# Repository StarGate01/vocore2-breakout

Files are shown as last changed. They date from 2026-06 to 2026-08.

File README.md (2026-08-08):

# vocore2-breakout

KiCad breakout board for the VoCore2 module (MT7628AN SoC).

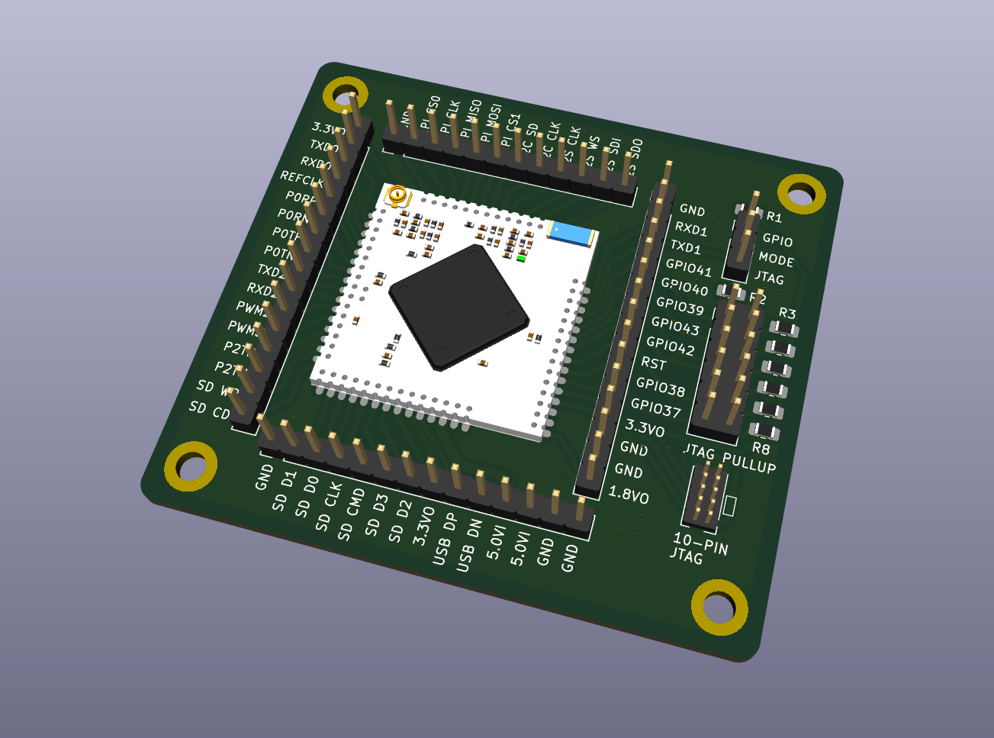
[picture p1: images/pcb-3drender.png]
PCB 3D render

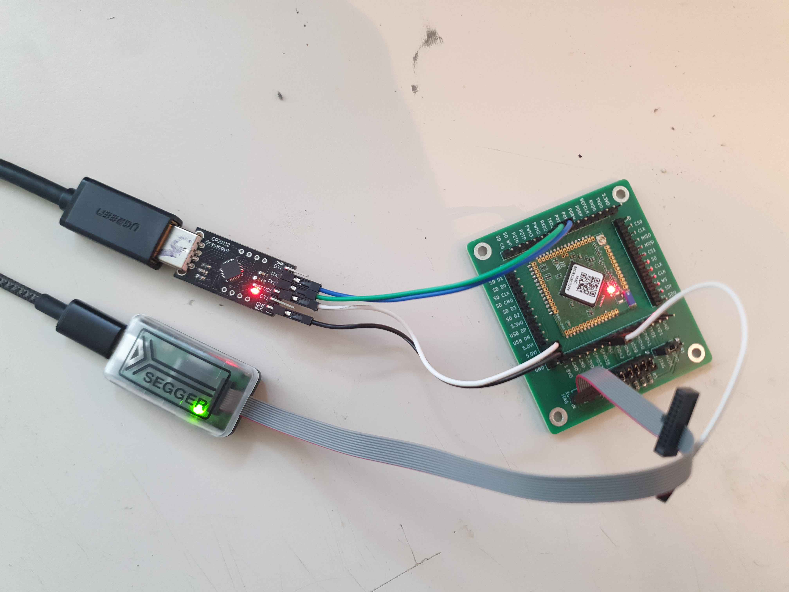
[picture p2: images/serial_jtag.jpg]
Serial and JTAG


## JTAG Connector (J-Link EDU Mini)

J6 is a 2×5 1.27 mm pitch header wired to the standard 9-pin ARM Cortex debug connector used by the J-Link EDU Mini.

| Pin | Signal | Notes |
|-----|---|---|
| 1 | `+3V3` | VTref - sense only, do not power board from here |
| 2 | `JTAG_TMS` | MT7628 `GPIO41` / `EPHY_LED2_N_JTMS` |
| 3 | `GND` | |
| 4 | `JTAG_CLK` | MT7628 `GPIO40` / `EPHY_LED3_N_JTCLK` |
| 5 | `GND` | |
| 6 | `JTAG_TDO` | MT7628 `GPIO43` / `EPHY_LED0_N_JTDO` |
| 7 | NC | KEY position - no pin on J-Link EDU Mini |
| 8 | `JTAG_TDI` | MT7628 `GPIO42` / `EPHY_LED1_N_JTDI` |
| 9 | `JTAG_TRST` | MT7628 `GPIO39` / `EPHY_LED4_N_JTRST_N` |
| 10 | `RESET` | MT7628 pin 138 / `PORST_N` (system reset, active-low) |

### J-Link EDU Mini reset pin specialities

The J-Link EDU Mini uses the **9-pin Cortex-M variant** of the connector, not the full 20-pin JTAG header:

- **Pin 7** is a physical key (no pin present). Not connected.
- **Pin 9** is repurposed by Segger as **nTRST** (JTAG TAP reset, active-low). In the standard Cortex-M spec pin 9 is NC; Segger uses it to support targets that need hardware TRST. Wire to `JTRST_N` (`GPIO39`).
- **Pin 10** is **nRESET** (system reset, active-low). Wire to `PORST_N`.

`WDT_RST_N` (`GPIO37` / MT7628 pin 137) appears adjacent to `PORST_N` and `JTRST_N` on the VoCore2 right-side connector and was considered for pin 9.

The vendor's JTAG how-to uses `WDT_RST_N` as "TRST" in their OpenOCD `sysfsgpio` config. This works because their setup is one VoCore2 bit-banging GPIOs to debug another - the host just needs two GPIO outputs to toggle, and driving `WDT_RST_N` low from an external GPIO triggers a full chip reset which also resets the JTAG TAP. OpenOCD's `sysfsgpio` driver doesn't care what hardware the signal is physically connected to; it just toggles the GPIO.

The J-Link is a hardware probe that follows the ARM Cortex debug connector spec strictly: pin 9 (`nTRST`) is driven by J-Link silicon to reset *only the JTAG TAP*, and the probe asserts and de-asserts it independently during normal debug sessions. If pin 9 connects to `WDT_RST_N`, every `nTRST` assertion by the J-Link triggers a full watchdog system reset, killing the debug session. `WDT_RST_N` is also a chip *output* when the watchdog fires, so the J-Link driving it creates a bus conflict. `JTRST_N` (`GPIO39`) resets only the TAP and has no output driver conflict.

### Pull-up resistors

All five JTAG signals (`TMS`, `TCK`, `TDI`, `TDO`, `TRST`) need pull-ups to 3V3. `RESET` (`PORST_N`) does not need external pull-ups from the breakout.

### OpenOCD configuration

OpenOCD requires third-party target scripts for the MT7628 - the standard script directory does not include this SoC. Clone [mtk-openwrt/openocd-scripts](https://github.com/mtk-openwrt/openocd-scripts) and point `OPENOCD_SCRIPTS` at it. This provides `mt7628.cfg` along with the `cpu_pll_init` and `dram_init` TCL helpers needed to bring up the PLL and DDR2 after halting the CPU via JTAG.

```sh
openocd -f interface/jlink.cfg \
        -c "transport select jtag" \
        -c "adapter speed 100" \
        -c "reset_config trst_and_srst separate srst_nogate connect_assert_srst" \
        -f mt7628.cfg \
        -c "init" \
        -c "reset halt" \
        -c "wait_halt 10000"
```

`adapter speed 100` - the MT7628 PLL is not running at reset; the JTAG clock source is the raw 40 MHz crystal. 100 kHz is conservative enough to be reliable in that window.

`reset_config trst_and_srst separate srst_nogate connect_assert_srst` - `connect_assert_srst` holds SRST (PORST_N) asserted when OpenOCD first connects, keeping the system in reset while the JTAG TAP initializes. `srst_nogate` keeps TCK running during SRST so OpenOCD can set the `EJTAGBOOT` instruction before releasing SRST. When SRST releases, the CPU starts with EJTAGBOOT active, enters the EJTAG debug ROM, and halts before its first instruction.

## TXD1 JTAG mode selector

MT7628 `GPIO13` / `TXD1` (VoCore2 pad `PR01`) is sampled at power-on reset to determine whether the `EPHY_LED` pins (`GPIO39`–`GPIO43`) operate as Ethernet LEDs or as the JTAG interface.

| `TXD1` at boot | Mode |
|---|---|
| HIGH (3V3) | Normal - `EPHY_LED` pins as Ethernet LEDs, **JTAG disabled** |
| LOW (GND) | **JTAG enabled** - `EPHY_LED` pins as `TMS`/`TCK`/`TDI`/`TDO`/`TRST` |

`JP1` is a 3-pin jumper with 4.7 kΩ resistors on both options:

| `JP1` position | `TXD1` | JTAG |
|---|---|---|
| 1-2 ("GPIO", default) | HIGH via `R1` (4K7 to `+3V3`) | Disabled |
| 2-3 ("JTAG") | LOW via `R2` (4K7 to `GND`) | **Enabled** |

Warning: JTAG mode breaks SD/eMMC on the EPHY pads.`TXD1` low (`DBG_JTAG_MODE=0`) does more than swap the `EPHY_LED` pins to JTAG, it puts the whole EPHY block into JTAG/debug state. If SD/eMMC is then muxed onto the EPHY pads ("IoT" mode, e.g. VoCore2's SD lines), the card stops responding. This is a hardware mutual-exclusion, not a software setting, JTAG and SD-on-EPHY cannot be used at the same time. Change the jumper after flashing to put the board into normal operation.

### VoCore2 module modification required

The stock VoCore2 module has **`R9` populated** (pull-up, 4.7 kΩ to 3V3) which holds `TXD1` high and disables JTAG. To use JTAG:

1. Remove `R9` from the VoCore2 module (eliminates the internal pull-up).
2. Set `JP` to position 2-3 on the breakout.

The breakout `JP` then has sole control over `TXD1` with no internal resistor fighting it. Leaving `R9` on the module while setting `JP` to 2-3 creates a voltage divider (~1.65 V, undefined logic level).

The original VoCore2 JTAG how-to describes moving `R9` to the `R6` footprint (a pull-down). With `R9` removed entirely and `JP` at 2-3, the effect is the same.

## Fabrication

Gerber files are in the `gerber/` directory and can be sent directly to a PCB manufacturer.

Before assembly, it is recommended to bake the VoCore2 module at 120 °C for at least 12 hours to drive out moisture. However it works just as well without.

The VoCore2 module must be reflowed using hot air, do not use a soldering iron. The DDR2 on the module is ESD-sensitive and iron leakage current can cause permanent damage. Reflow temperature must not exceed 260 °C for more than 10 seconds.

The resistors can be reflowed together with the VoCore2 module or soldered normally with an iron. The through-hole pin headers are soldered normally. Take special care with the JTAG header (J6): it uses a 1.27 mm pitch fine-pitch header where adjacent pins are easy to bridge accidentally. Inspect with a loupe or microscope after soldering.

## References

- [J-Link EDU Mini KB](https://kb.segger.com/J-Link_EDU_Mini)
- [9-pin JTAG/SWD connector](https://kb.segger.com/9-pin_JTAG/SWD_connector)
- [VoCore2 pinout](https://vocore.io/v2.html)
- [VoCore2 JTAG how-to](https://vonger.cn/?p=14897)

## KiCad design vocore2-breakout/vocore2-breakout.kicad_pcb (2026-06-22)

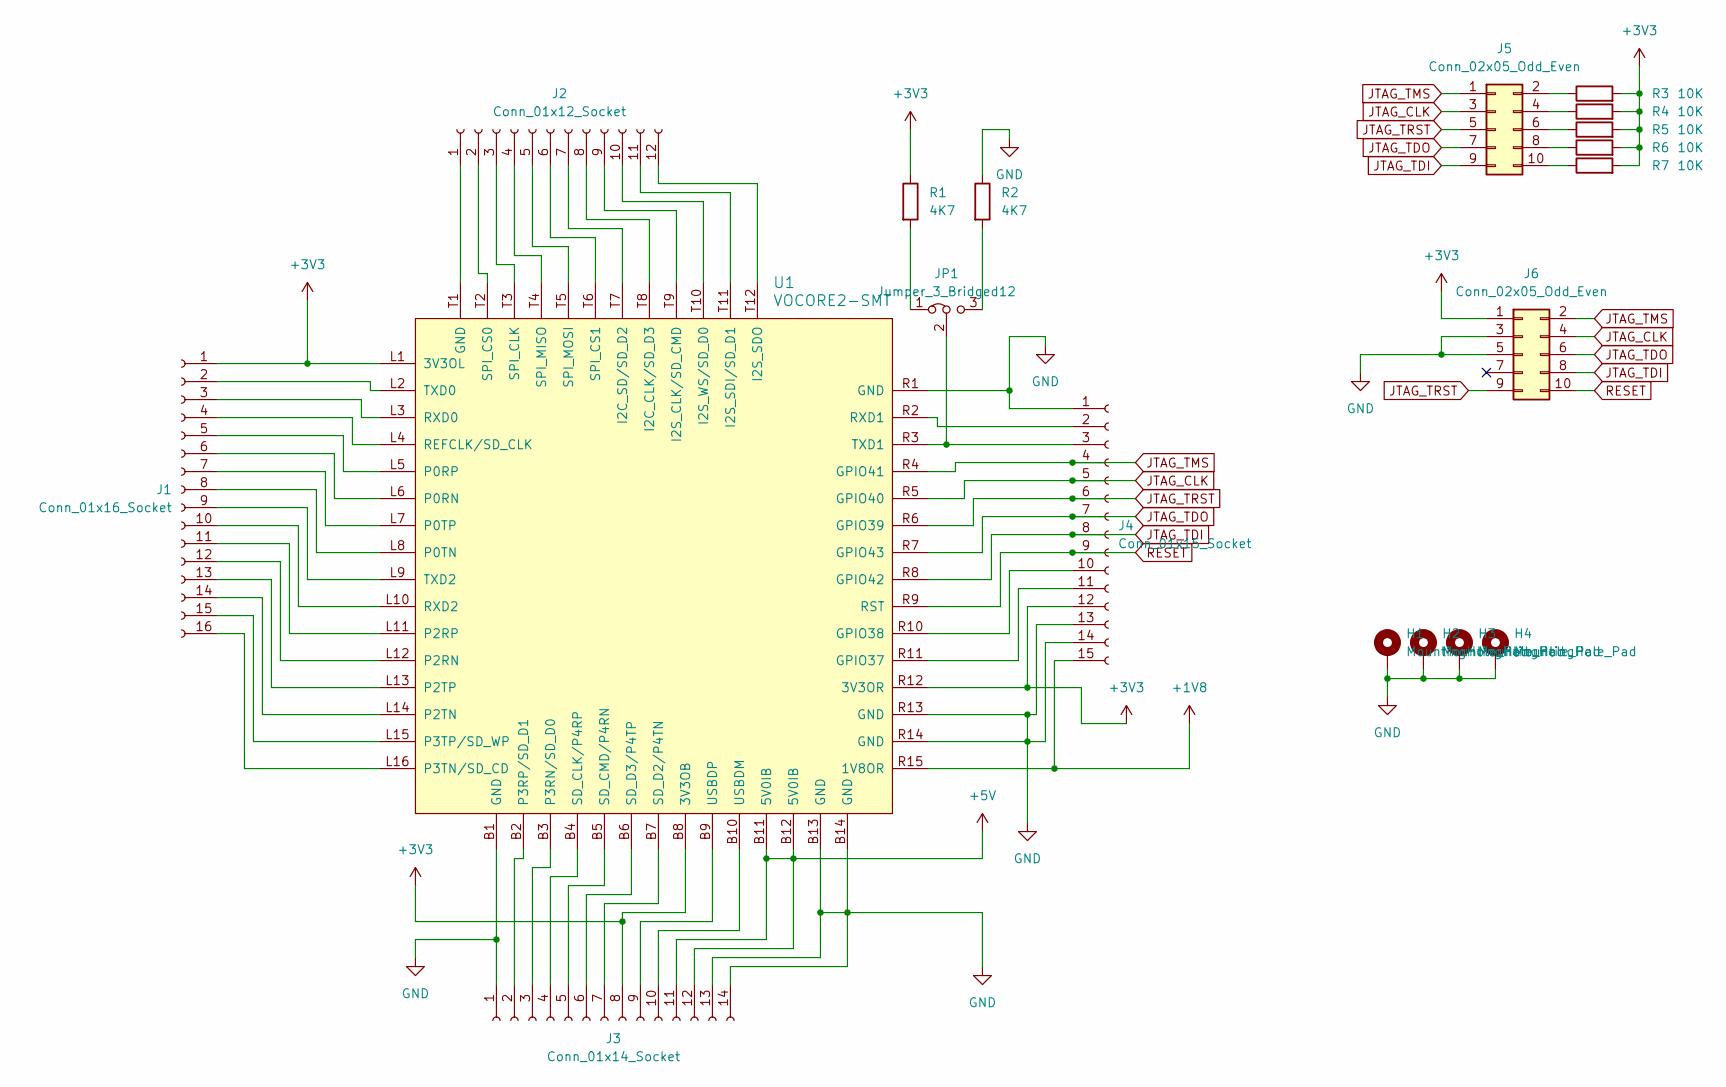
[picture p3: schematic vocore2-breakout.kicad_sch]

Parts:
H1, H2, H3, H4: MountingHole_Pad; MountingHole_3.2mm_M3_DIN965_Pad
J1: Conn_01x16_Socket; PinHeader_1x16_P2.54mm_Vertical
J2: Conn_01x12_Socket; PinHeader_1x12_P2.54mm_Vertical
J3: Conn_01x14_Socket; PinHeader_1x14_P2.54mm_Vertical
J4: Conn_01x15_Socket; PinHeader_1x15_P2.54mm_Vertical
J5: Conn_02x05_Odd_Even; PinHeader_2x05_P2.54mm_Vertical
J6: Conn_02x05_Odd_Even; PinHeader_2x05_P1.27mm_Vertical
JP1: Jumper_3_Bridged12; PinHeader_1x03_P2.54mm_Vertical
R1, R2: 4K7; R_0805_2012Metric_Pad1.20x1.40mm_HandSolder
R3, R4, R5, R6, R7: 10K; R_0805_2012Metric_Pad1.20x1.40mm_HandSolder
U1: VOCORE2-SMT

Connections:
+1V8: J4.15, U1.R15 (1V8OR)
+3V3: J1.1, J3.8, J4.12, J6.1, R1.1, R3.2, R4.2, R5.2, R6.2, R7.2, U1.B8 (3V3OB), U1.L1 (3V3OL), U1.R12 (3V3OR)
+5V: J3.11, J3.12, U1.B11 (5V0IB), U1.B12 (5V0IB)
GND: H1.1 (1_1), H2.1 (1_1), H3.1 (1_1), H4.1 (1_1), J3.1, J3.13, J3.14, J4.1, J4.13, J4.14, J6.3, J6.5, R2.1, U1.B1 (GND), U1.B13 (GND), U1.B14 (GND), U1.R1 (GND), U1.R13 (GND), U1.R14 (GND)
JTAG_CLK: J4.5, J5.3, J6.4, U1.R5 (GPIO40)
JTAG_TDI: J4.8, J5.9, J6.8, U1.R8 (GPIO42)
JTAG_TDO: J4.7, J5.7, J6.6, U1.R7 (GPIO43)
JTAG_TMS: J4.4, J5.1, J6.2, U1.R4 (GPIO41)
JTAG_TRST: J4.6, J5.5, J6.9, U1.R6 (GPIO39)
unnamed: J1.2, U1.L2 (TXD0)
unnamed: J1.3, U1.L3 (RXD0)
unnamed: J1.4, U1.L4 (REFCLK/SD_CLK)
unnamed: J1.5, U1.L5 (P0RP)
unnamed: J1.6, U1.L6 (P0RN)
unnamed: J1.7, U1.L7 (P0TP)
unnamed: J1.8, U1.L8 (P0TN)
unnamed: J1.9, U1.L9 (TXD2)
unnamed: J1.10, U1.L10 (RXD2)
unnamed: J1.11, U1.L11 (P2RP)
unnamed: J1.12, U1.L12 (P2RN)
unnamed: J1.13, U1.L13 (P2TP)
unnamed: J1.14, U1.L14 (P2TN)
unnamed: J1.15, U1.L15 (P3TP/SD_WP)
unnamed: J1.16, U1.L16 (P3TN/SD_CD)
unnamed: J2.1, U1.T1 (GND)
unnamed: J2.2, U1.T2 (SPI_CS0)
unnamed: J2.3, U1.T3 (SPI_CLK)
unnamed: J2.4, U1.T4 (SPI_MISO)
unnamed: J2.5, U1.T5 (SPI_MOSI)
unnamed: J2.6, U1.T6 (SPI_CS1)
unnamed: J2.7, U1.T7 (I2C_SD/SD_D2)
unnamed: J2.8, U1.T8 (I2C_CLK/SD_D3)
unnamed: J2.9, U1.T9 (I2S_CLK/SD_CMD)
unnamed: J2.10, U1.T10 (I2S_WS/SD_D0)
unnamed: J2.11, U1.T11 (I2S_SDI/SD_D1)
unnamed: J2.12, U1.T12 (I2S_SDO)
unnamed: J3.2, U1.B2 (P3RP/SD_D1)
unnamed: J3.3, U1.B3 (P3RN/SD_D0)
unnamed: J3.4, U1.B4 (SD_CLK/P4RP)
unnamed: J3.5, U1.B5 (SD_CMD/P4RN)
unnamed: J3.6, U1.B6 (SD_D3/P4TP)
unnamed: J3.7, U1.B7 (SD_D2/P4TN)
unnamed: J3.9, U1.B9 (USBDP)
unnamed: J3.10, U1.B10 (USBDM)
unnamed: J4.2, U1.R2 (RXD1)
unnamed: J4.3, JP1.2 (C), U1.R3 (TXD1)
unnamed: J4.10, U1.R10 (GPIO38)
unnamed: J4.11, U1.R11 (GPIO37)
unnamed: J5.2, R3.1
unnamed: J5.4, R4.1
unnamed: J5.6, R5.1
unnamed: J5.8, R6.1
unnamed: J5.10, R7.1
unnamed: JP1.1 (A), R1.2
unnamed: JP1.3 (B), R2.2
RESET: J4.9, J6.10, U1.R9 (RST)

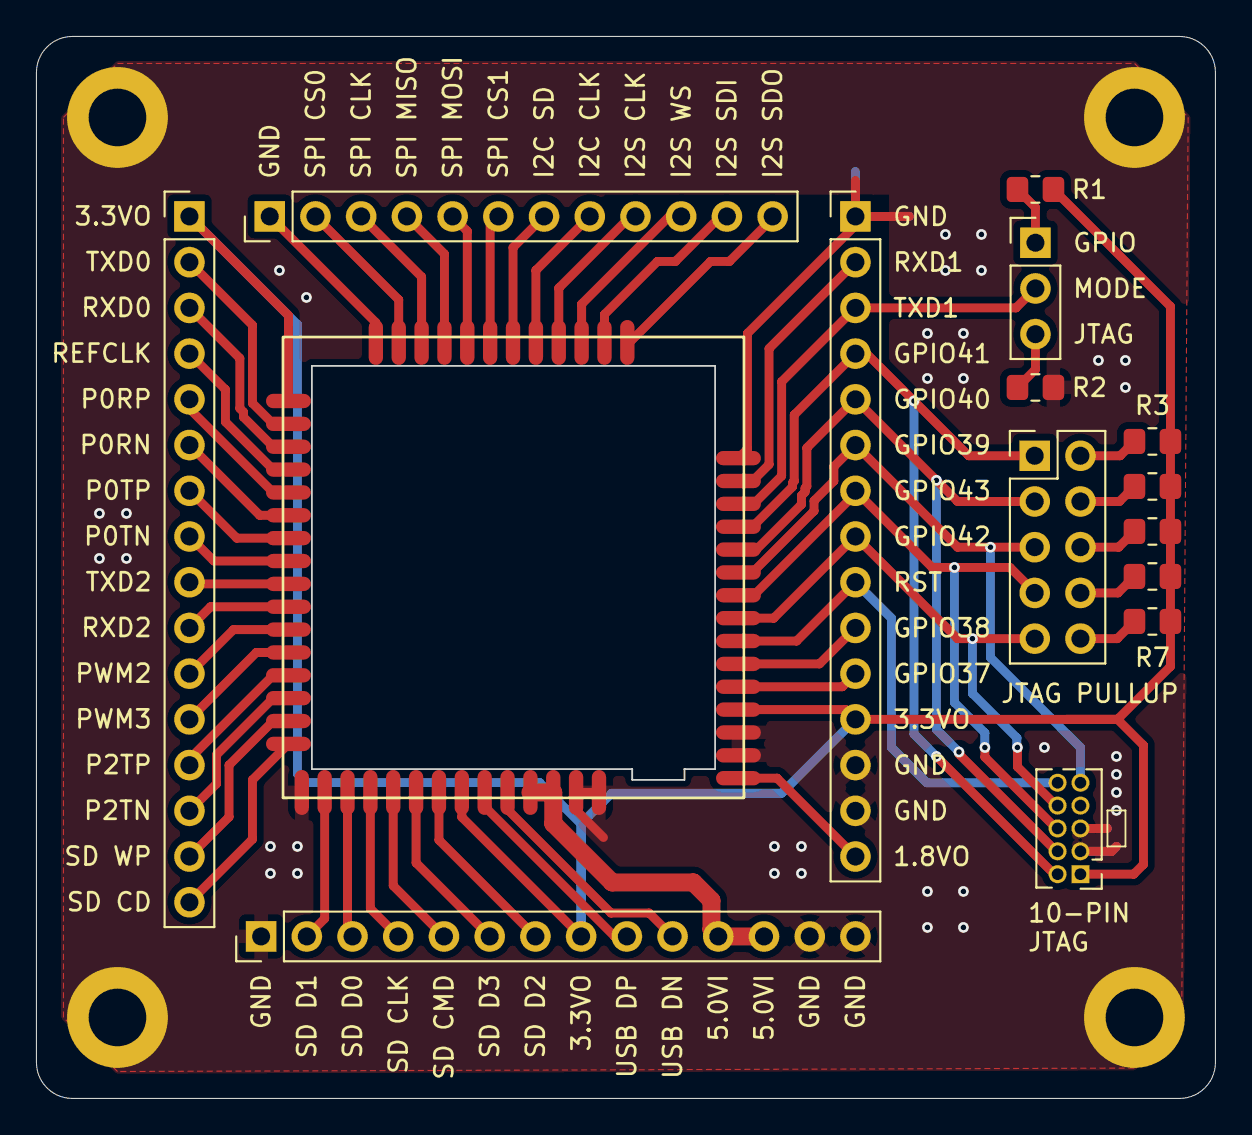
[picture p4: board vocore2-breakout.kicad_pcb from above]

Board: 2 copper layers, 65.5 x 59.0 mm, 19 parts (0 on the bottom side), 56 nets.

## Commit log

2026-06-18 Add kicad files
    [vocore2-breakout.kicad_pcb, vocore2-breakout.kicad_sch]
2026-06-19 Use correct jtag reset
    [vocore2-breakout.kicad_pcb, vocore2-breakout.kicad_sch]
2026-06-22 Export gerber files
    [vocore2-breakout-B_Cu.gbl, vocore2-breakout-B_Mask.gbs, vocore2-breakout-B_Silkscreen.gbo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]
